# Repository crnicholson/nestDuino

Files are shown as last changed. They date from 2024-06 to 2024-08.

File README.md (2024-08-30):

# nestDuino

nestDuino Image

nestDuino is an Arduino kit designed to be soldered and assembled. This will hopefully teach the youth at New England Sci-Tech (NEST) more about electronics in the process of learning embedded engineering with Arduino. The kit is meant to be low cost and a drop-in replacement for the Arduino Uno, keeping all the same functionality, but with all through hole components, besides the AMS1117, for ease of assembly.

# License

nestDuino has no license. 

All rights reserved. Copyright New England Sci-Tech and Charles Nicholson 2024.

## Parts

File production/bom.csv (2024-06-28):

Designator | Footprint | Quantity | Value | LCSC Part #
C1, C10, C12, C2, C5, C6, C8 | C_Disc_D4.3mm_W1.9mm_P5.00mm | 7 | 100 nF
C11 | C_Disc_D4.3mm_W1.9mm_P5.00mm | 1 | 330 nF
C3, C4 | C_Disc_D4.3mm_W1.9mm_P5.00mm | 2 | 22 pF
C7 | C_Disc_D4.3mm_W1.9mm_P5.00mm | 1 | 10 uF
C9 | CP_Radial_D5.0mm_P2.00mm | 1 | 10 uF
D1 | LED_D3.0mm | 1 | Pin 13
D2 | LED_D3.0mm | 1 | Power
J1 | PinSocket_1x08_P2.54mm_Vertical | 1 | Power
J2 | PinSocket_1x10_P2.54mm_Vertical | 1 | Digital/PWM
J3 | PinSocket_1x06_P2.54mm_Vertical | 1 | Analog
J4 | PinSocket_1x08_P2.54mm_Vertical | 1 | Digital/PWM
J5 | PinSocket_1x06_P2.54mm_Horizontal | 1 | FTDI
J6 | BarrelJack_Horizontal | 1 | Barrel_Jack_Switch
J7 | PinHeader_2x03_P2.54mm_Vertical | 1 | ISP
R1 | R_Axial_DIN0207_L6.3mm_D2.5mm_P10.16mm_Horizontal | 1 | 10 K
R2, R3 | R_Axial_DIN0207_L6.3mm_D2.5mm_P10.16mm_Horizontal | 2 | 1 K
SW1 | SW_PUSH_6mm | 1 | Reset
U1 | SOT-223-3_TabPin2 | 1 | AMS1117-3.3
U2 | DIP-28_W7.62mm | 1 | ATmega328P-P
U3 | TO-220-3_Horizontal_TabDown | 1 | L7805CV | L7805CV
Y1 | Crystal_HC49-U_Vertical | 1 | 8 MHz

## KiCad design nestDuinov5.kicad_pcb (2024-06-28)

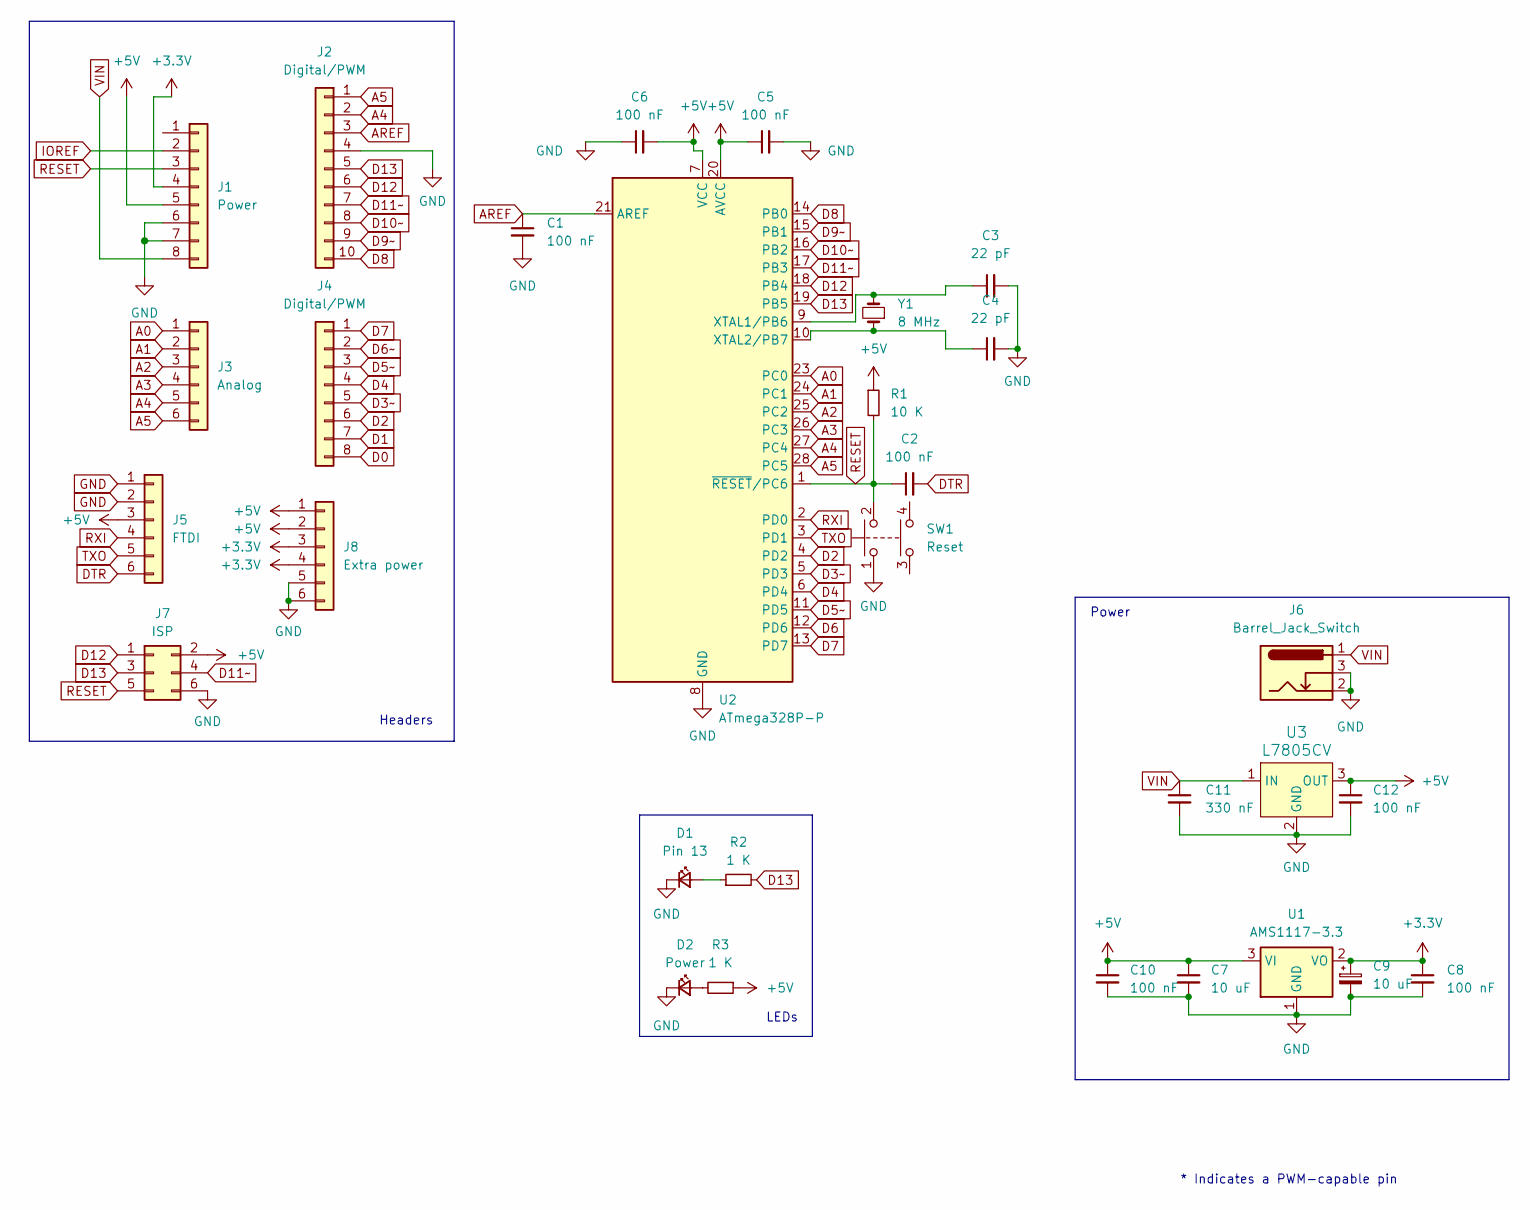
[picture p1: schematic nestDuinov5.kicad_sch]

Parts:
C1, C2, C5, C6, C8, C10, C12: 100 nF; C_Disc_D4.3mm_W1.9mm_P5.00mm
C3, C4: 22 pF; C_Disc_D4.3mm_W1.9mm_P5.00mm
C7: 10 uF; C_Disc_D4.3mm_W1.9mm_P5.00mm
C9: 10 uF; CP_Radial_D5.0mm_P2.00mm
C11: 330 nF; C_Disc_D4.3mm_W1.9mm_P5.00mm
D1: Pin 13; LED_D3.0mm
D2: Power; LED_D3.0mm
J1: Power; PinSocket_1x08_P2.54mm_Vertical
J2: Digital/PWM; PinSocket_1x10_P2.54mm_Vertical
J3: Analog; PinSocket_1x06_P2.54mm_Vertical
J4: Digital/PWM; PinSocket_1x08_P2.54mm_Vertical
J5: FTDI; PinSocket_1x06_P2.54mm_Horizontal
J6: Barrel_Jack_Switch; BarrelJack_Horizontal
J7: ISP; PinHeader_2x03_P2.54mm_Vertical
J8: Extra power; PinSocket_1x06_P2.54mm_Vertical
R1: 10 K; R_Axial_DIN0207_L6.3mm_D2.5mm_P10.16mm_Horizontal
R2, R3: 1 K; R_Axial_DIN0207_L6.3mm_D2.5mm_P10.16mm_Horizontal
SW1: Reset; SW_PUSH_6mm
U1: AMS1117-3.3; SOT-223-3_TabPin2
U2: ATmega328P-P; DIP-28_W7.62mm
U3: L7805CV; TO-220-3_Horizontal_TabDown; MPN L7805CV; Digi-Key_PN 497-1443-5-ND
Y1: 8 MHz; Crystal_HC49-U_Vertical

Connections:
+3.3V: C8.1, C9.1, J1.4, J8.3, J8.4, U1.2 (VO)
+5V: C5.1, C6.2, C7.1, C10.1, C12.1, J1.5, J5.3, J7.2, J8.1, J8.2, R1.1, R3.1, U1.3 (VI), U2.7 (VCC), U2.20 (AVCC), U3.3 (OUT)
A0: J3.1, U2.23 (PC0)
A1: J3.2, U2.24 (PC1)
A2: J3.3, U2.25 (PC2)
A3: J3.4, U2.26 (PC3)
A4: J2.2, J3.5, U2.27 (PC4)
A5: J2.1, J3.6, U2.28 (PC5)
AREF: C1.1, J2.3, U2.21 (AREF)
D0: J4.8
D1: J4.7
D2: J4.6, U2.4 (PD2)
D3~: J4.5, U2.5 (PD3)
D4: J4.4, U2.6 (PD4)
D5~: J4.3, U2.11 (PD5)
D6: U2.12 (PD6)
D6~: J4.2
D7: J4.1, U2.13 (PD7)
D8: J2.10, U2.14 (PB0)
D9~: J2.9, U2.15 (PB1)
D10~: J2.8, U2.16 (PB2)
D11~: J2.7, J7.4, U2.17 (PB3)
D12: J2.6, J7.1, U2.18 (PB4)
D13: J2.5, J7.3, R2.2, U2.19 (PB5)
DTR: C2.2, J5.6
GND: C1.2, C3.2, C4.2, C5.2, C6.1, C7.2, C8.2, C9.2, C10.2, C11.2, C12.2, D1.1 (K), D2.1 (K), J1.6, J1.7, J2.4, J5.1, J5.2, J6.2, J6.3, J7.6, J8.5, J8.6, SW1.1, U1.1 (GND), U2.8 (GND), U3.2 (GND)
IOREF: J1.2
unnamed: D1.2 (A), R2.1
unnamed: D2.2 (A), R3.2
unnamed: C3.1, U2.9 (XTAL1/PB6), Y1.2
unnamed: C4.1, U2.10 (XTAL2/PB7), Y1.1
RESET: C2.1, J1.3, J7.5, R1.2, SW1.2, U2.1 (~RESET/PC6)
RXI: J5.4, U2.2 (PD0)
TXO: J5.5, U2.3 (PD1)
VIN: C11.1, J1.8, J6.1, U3.1 (IN)

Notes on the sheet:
* Indicates a PWM-capable pin
Power
LEDs
Headers

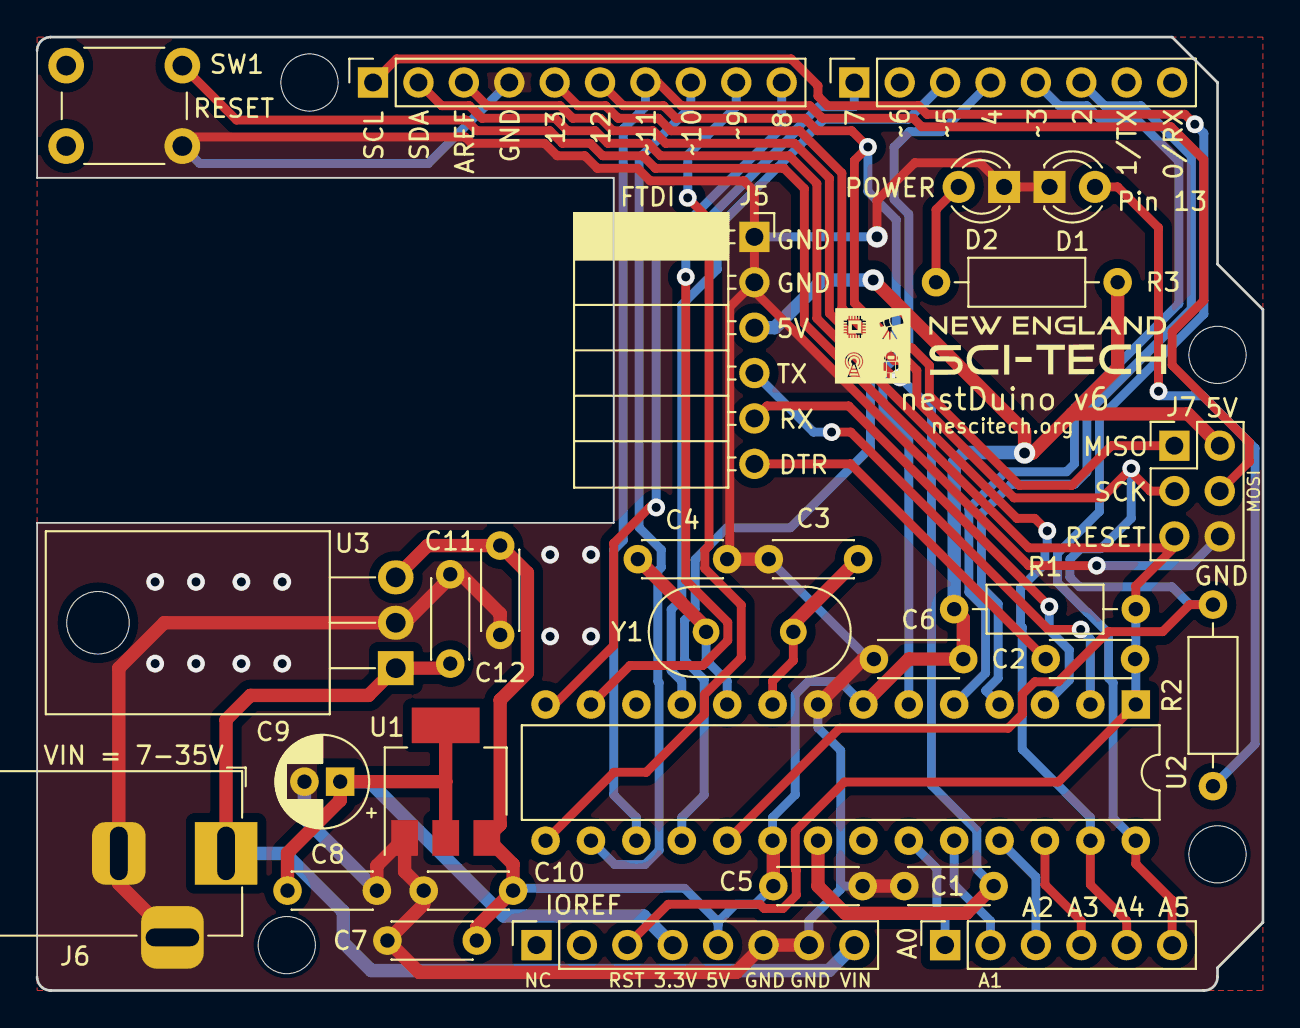
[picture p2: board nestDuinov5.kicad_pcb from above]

Board: 2 copper layers, 68.6 x 53.3 mm, 33 parts (0 on the bottom side), 30 nets.

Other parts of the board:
MH1, MH2, MH3, MH4: MountingHole_3.2mm
